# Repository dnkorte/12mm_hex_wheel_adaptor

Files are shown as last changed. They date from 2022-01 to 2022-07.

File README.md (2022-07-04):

# 12mm Hex Nut Wheel Adaptor

<h1 align="center">
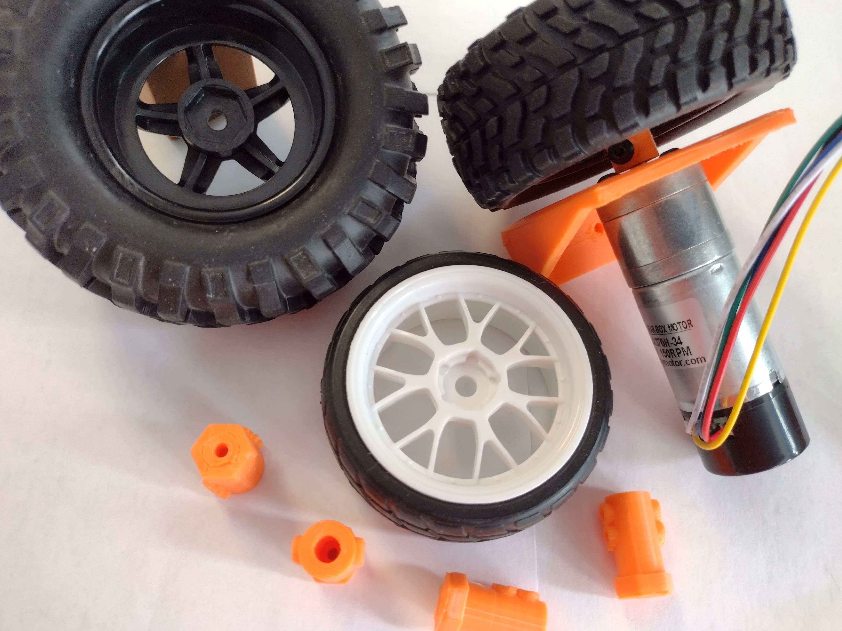
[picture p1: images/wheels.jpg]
Picture of wheels and adaptors
	<br>Sample Wheels and adaptors
</h1>

The RC (Radio Control) cars and truck hobbiest market has made be-zillions of tires/wheels available in various sizes, styles, and materials.  Just go to Amazon or  your favorite hobby store to find a huge variety.  The industry has a pretty standard mounting configuration which is based on a 12mm hex nut.  The wheels have a "socket" to hold the 12mm nut, and most RC vehicles have axles (or axle adaptors) that will fit to those nuts.  Typically the wheels attach to the 12mm nut by means of a screw at wheel center.

This project creates 3d-printable hub adaptors that mate those 12mm hex nuts to typical motor shafts used in hobby robotics -- 4mm, 5mm, and 6mm round shafts, as well as the common TT motor flattened shaft.

They are created in OpenSCAD, which is a text-based CAD tool that runs on Windows, Linux, and MAC (download it from https://openscad.org/ if you don't have it already).  Put the file provided here ("project_12mm_hex_wheel_adaptors.scad") in a folder on your computer, then open it in OpenSCAD.  Note that this tool is setup to use OpenSCAD's "customizer" feature to select the part you want, but this tool is hidden by default.  To show the customizer, just go to OpenSCAD's "View" menu and uncheck the "Hide Customizer" checkbox.

Once the customizer is visible you will see some dropdowns available (probably on the right side of your screen).  Select the "part" you want to create from the "part" dropdown (you can select the 4mm, 5mm, 6mm, or TT shaft version).  You may also select a "hub length" parameter that defines how long the adaptor is (wide tires will need longer adaptors than skinny tires), and the location for the "grub screws" that will help attach the adaptor to your motor shaft.

Whenever you change any of the dropdowns, it will redraw the image on screen.  When you have the adaptor as you wish it, click F6 or "Design/Render" on the menubar to make a finished render of the model, then select "File/Export" to save an .stl file for your printer.

The adaptor has a central hole at the "nut" end that is co-axial to the motor shaft -- this hole accepts an M3 screw to attach the adaptor to the wheel.  All screw holes are designed to be self-tapping for M3 bolts.

If your printer tolerances are different than mine you may adjust the size of the screw holes or the shaft clearance holes by editing the project_12mm_hex_wheel_adaptors.scad file.  The relevant lines are 74-84; parameters are screwhole_radius_M30_passthru, screwhole_radius_M30_selftap, and axle_clearance_gap.

The image below shows the OpenSCAD screen.  Note the Customizer menu on the right side.

<h3 align="center">
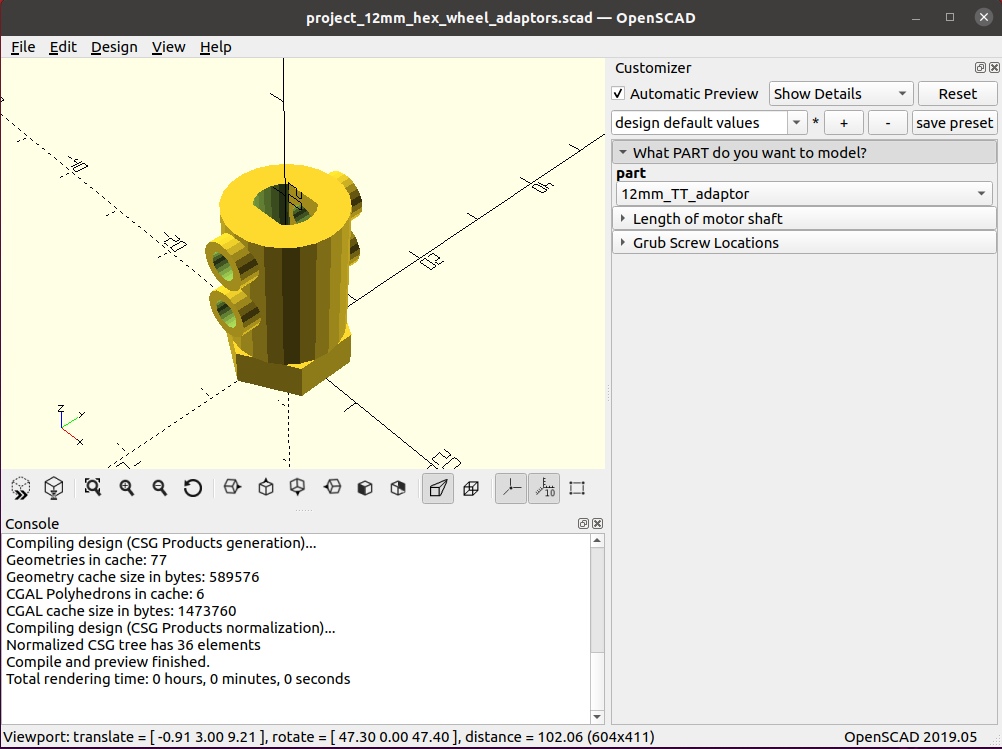
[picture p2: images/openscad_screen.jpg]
	<br>OpenSCAD screen
</h3>

The image below shows a wheel mounted on a motor shaft.
<h3 align="center">
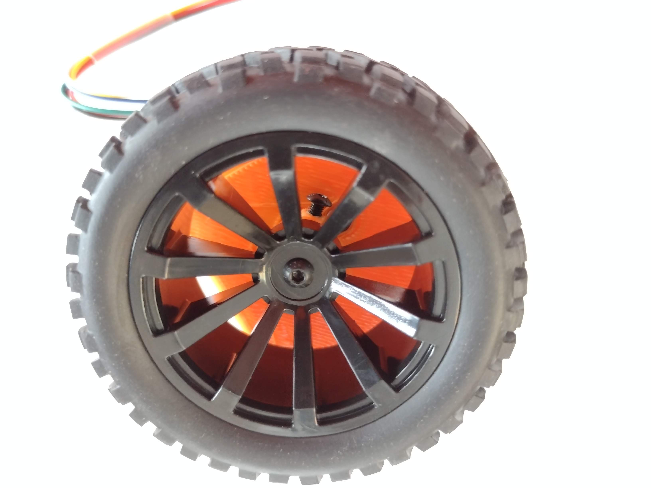
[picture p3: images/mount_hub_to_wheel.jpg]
	<br>Wheel mounted on adaptor
</h3>

A couple pre-built .stl files are included in the .stl folder here. Note that the hubs are best printed in the vertical orientation with nut end down.  They should be printed fairly slowly for best results.  

### Some sample wheels</h3>
Just as an example, some of the wheels I have used are shown here
* 95mm x 38mm wide : https://www.amazon.com/Buggy-Rubber-Tires-Spoke-Wheel/dp/B00W10IJEG  
* 76mm x 30mm wide : https://www.amazon.com/4-Pack-HobbyPark-2-99-inch-Rubber/dp/B071ZX9JB7 
* 63mm x 25mm wide : https://www.amazon.com/Tires-Wheels-Rims-Shaped-Width/dp/B01MTSMNAZ 

### Purchasable Brass Adaptors
If you prefer to use machined brass adaptors, here are some available for purchase (these are all for 12mm hex wheel end)
* 6mm motor shaft : https://www.piborg.org/motors-mounts-and-wheels-1140/hub-6mm
* 5mm motor shaft : https://www.piborg.org/motors-mounts-and-wheels-1140/hub-5mm
* 4mm motor shaft : https://www.piborg.org/motors-mounts-and-wheels-1140/hub-4mm
* 3mm motor shaft : https://www.piborg.org/motors-mounts-and-wheels-1140/hub-3mm
* 5mm motor shaft (8 pcs) : https://www.amazon.com/uxcell-Coupler-Coupling-Flexible-Connector/dp/B08M3H71SW
* 4mm motor shaft (8 pcs) : https://www.amazon.com/uxcell-Coupler-Coupling-Flexible-Connector/dp/B08M3Z2N8B

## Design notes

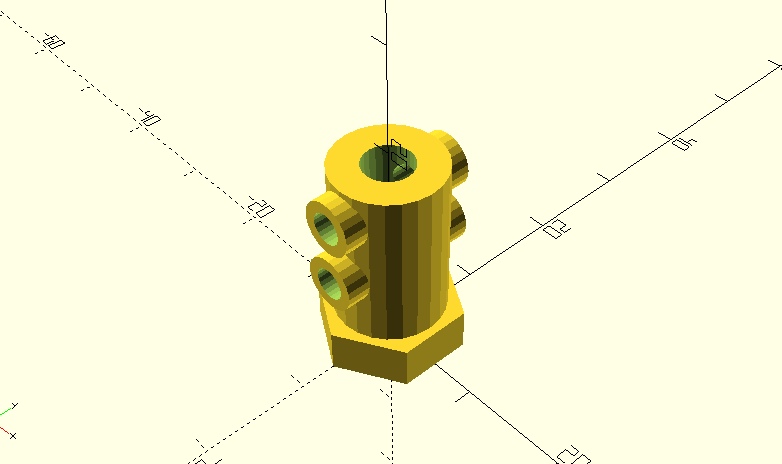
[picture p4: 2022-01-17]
images/4mm_shaft_openscad.jpg

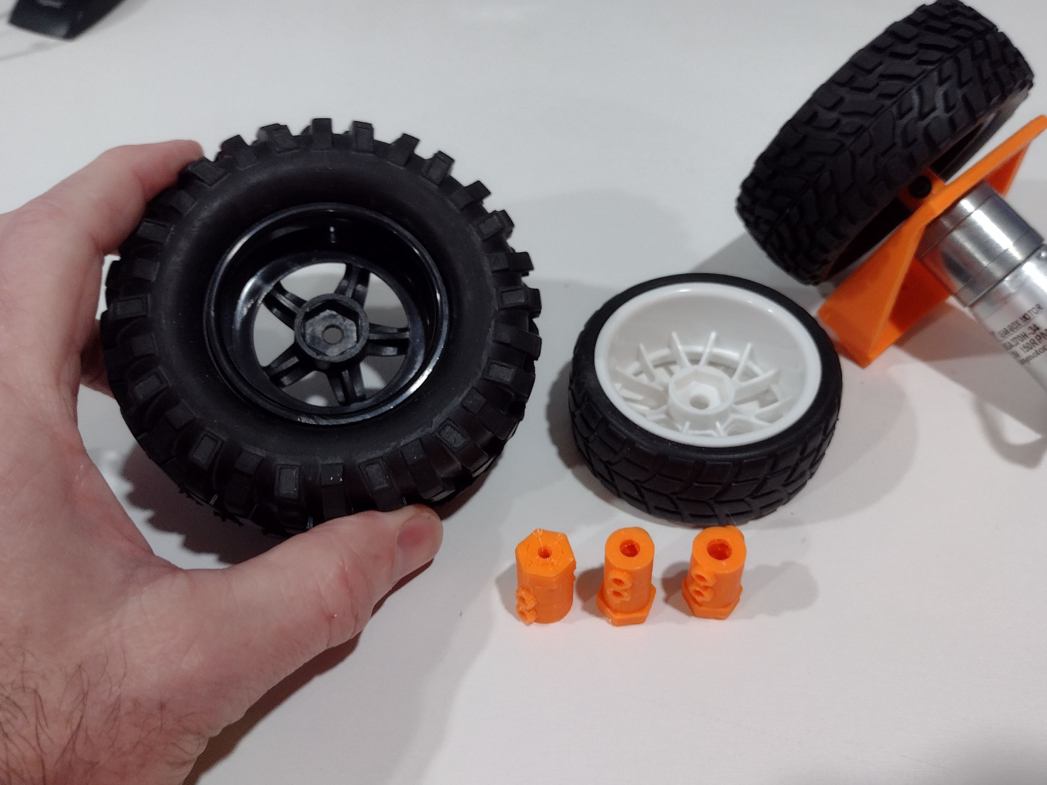
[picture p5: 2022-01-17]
images/sample_wheels.jpg

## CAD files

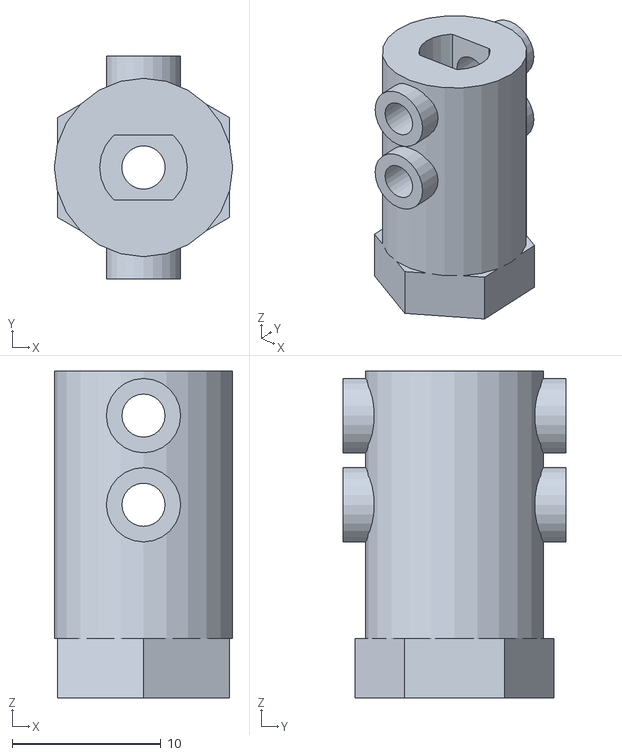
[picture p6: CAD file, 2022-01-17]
stls/TT_18mm.stl
12.0 x 15.0 x 22.0

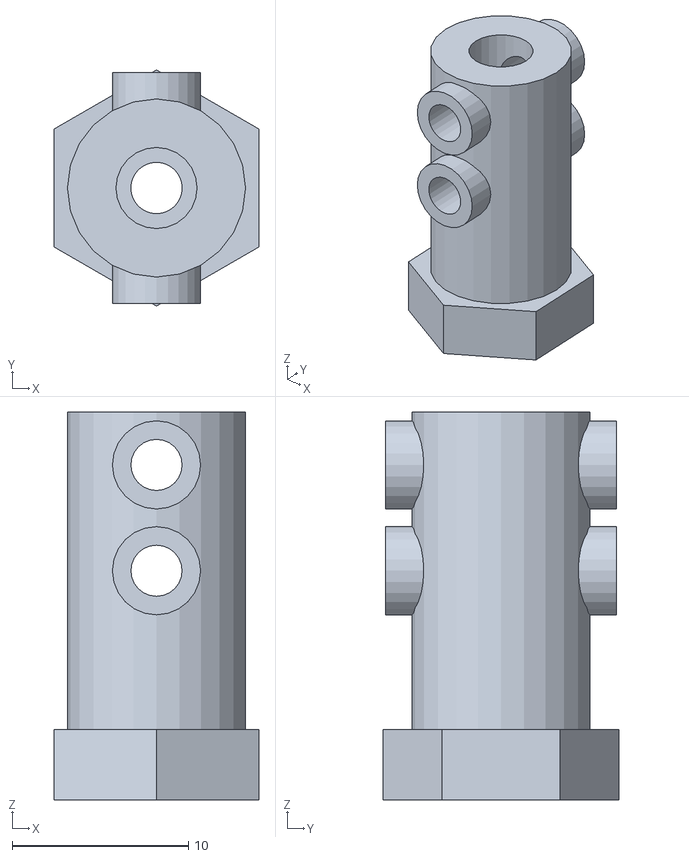
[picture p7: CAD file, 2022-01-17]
stls/4mm_axle_18mm.stl
11.6 x 13.4 x 22.0

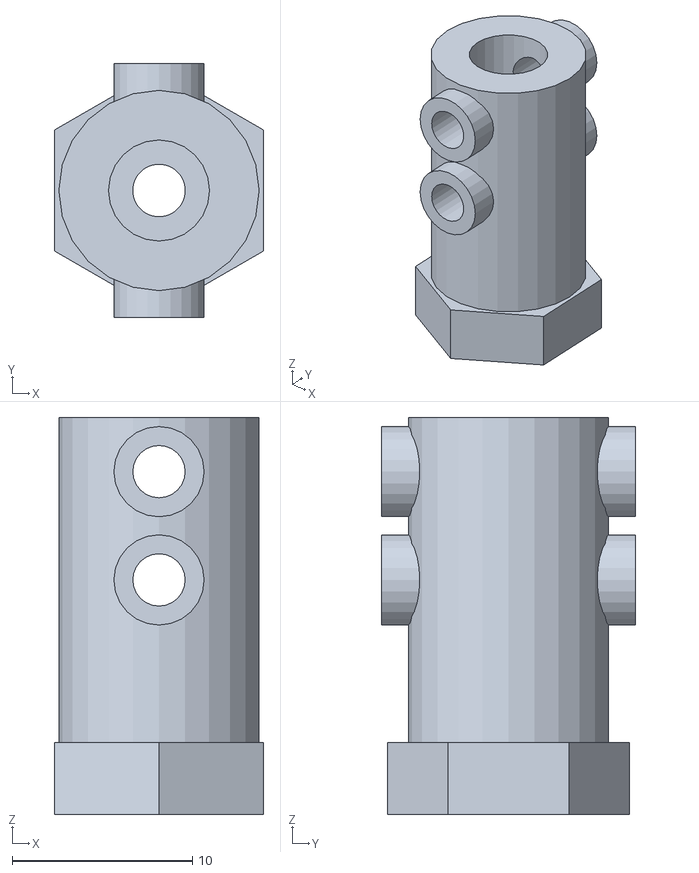
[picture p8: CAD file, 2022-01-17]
stls/5mm_axle_18mm.stl
11.6 x 14.1 x 22.0

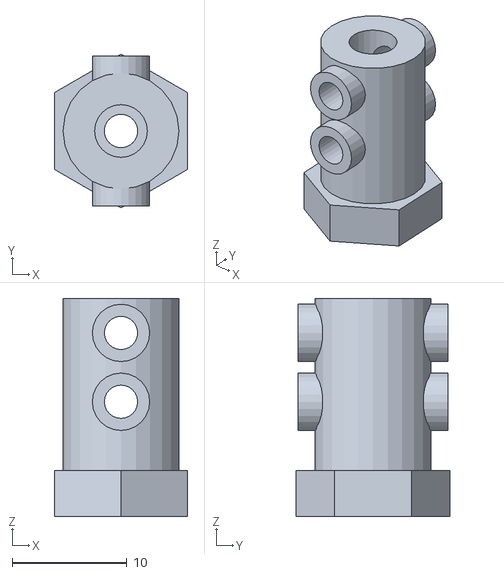
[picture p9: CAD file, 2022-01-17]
stls/4mm_axle_15mm.stl
11.6 x 13.4 x 19.0

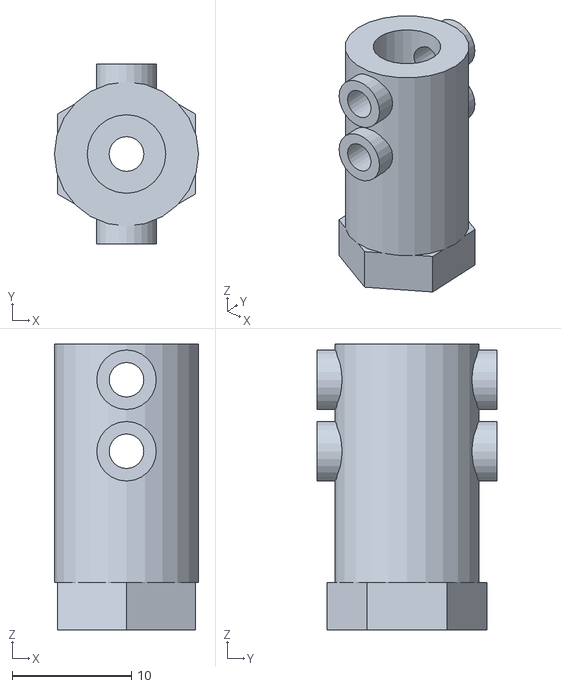
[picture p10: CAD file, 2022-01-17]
stls/6mm_axle_12mm.stl
12.1 x 15.1 x 24.0

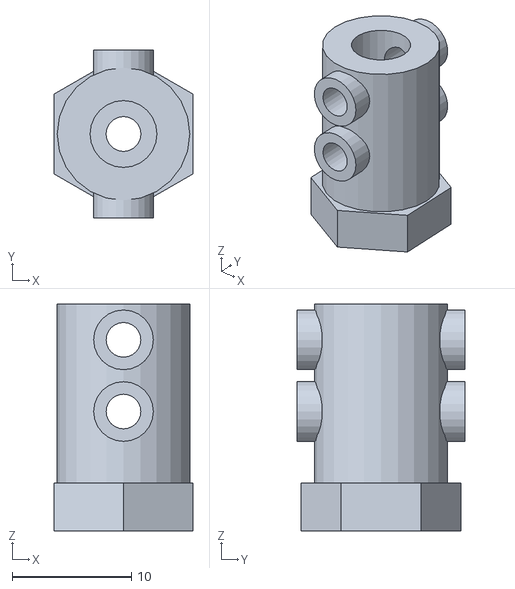
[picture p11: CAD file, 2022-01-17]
stls/5mm_axle_15mm.stl
11.6 x 14.1 x 19.0

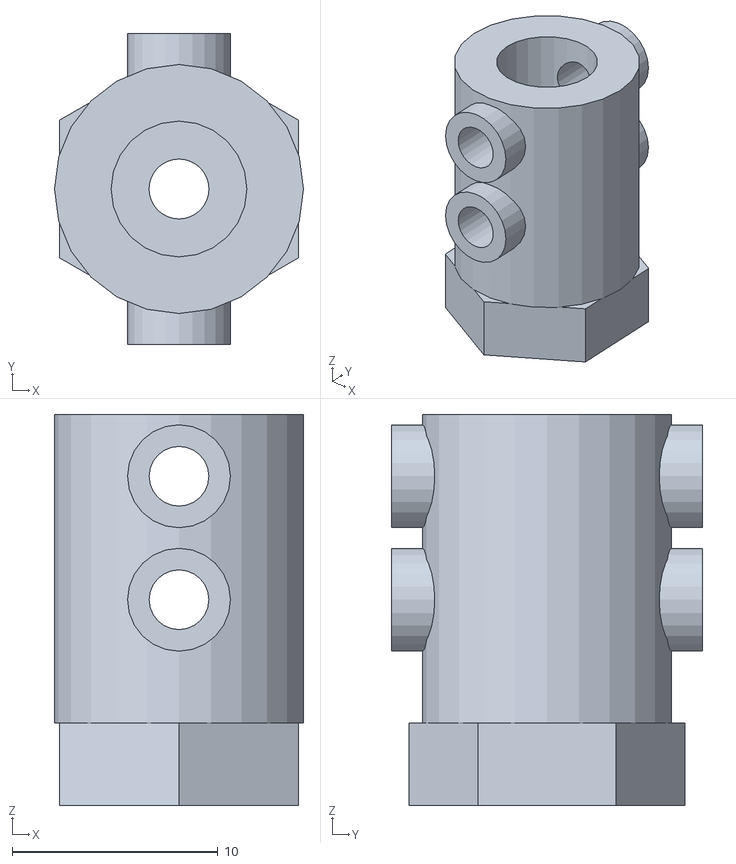
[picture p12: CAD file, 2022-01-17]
stls/6mm_axle_18mm.stl
12.1 x 15.1 x 19.0

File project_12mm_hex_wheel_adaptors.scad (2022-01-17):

/*
 * Module: project_12mm_hex_wheel_adaptors.scad
 * this generates an adaptor the connects standard RC wheel 12mm hex nut
 *   wheels to standard robotics motor hubs  
 *
 *   NOTE that hub adaptors should be printed slowly -- about 50% normal print speed 
 *
 * Author(s): Don Korte 
 *
 * github: https://github.com/dnkorte/
 *  
 * MIT License
 * 
 * Copyright (c) 2022 Don Korte
 * 
 * Permission is hereby granted, free of charge, to any person obtaining a copy
 * of this software and associated documentation files (the "Software"), to deal
 * in the Software without restriction, including without limitation the rights
 * to use, copy, modify, merge, publish, distribute, sublicense, and/or sell
 * copies of the Software, and to permit persons to whom the Software is
 * furnished to do so, subject to the following conditions:
 * 
 * The above copyright notice and this permission notice shall be included in all
 * copies or substantial portions of the Software.
 * 
 * THE SOFTWARE IS PROVIDED "AS IS", WITHOUT WARRANTY OF ANY KIND, EXPRESS OR
 * IMPLIED, INCLUDING BUT NOT LIMITED TO THE WARRANTIES OF MERCHANTABILITY,
 * FITNESS FOR A PARTICULAR PURPOSE AND NONINFRINGEMENT. IN NO EVENT SHALL THE
 * AUTHORS OR COPYRIGHT HOLDERS BE LIABLE FOR ANY CLAIM, DAMAGES OR OTHER
 * LIABILITY, WHETHER IN AN ACTION OF CONTRACT, TORT OR OTHERWISE, ARISING FROM,
 * OUT OF OR IN CONNECTION WITH THE SOFTWARE OR THE USE OR OTHER DEALINGS IN THE
 * SOFTWARE.
 */


/* [What PART do you want to model?] */
part = "12mm_4mm_adaptor";  // [ "12mm_6mm_adaptor", "12mm_5mm_adaptor", "12mm_4mm_adaptor", "12mm_TT_adaptor" ]

/* [Length of motor shaft] */
// length of "round" part of adaptor that surrounds axle
hub_len = 15;   // [12, 15, 18, 20 ]

/* [Grub Screw Locations] */
// distance of "first" grub screw from end of adaptor
grubscrew_dist_from_end = 3;    // [ 3, 4, 5, 6 ]
// distance between grub screws
grubscrew_separation = 6;       // [ 5, 6, 7, 8 ] 

draw_part();

module draw_part() {
    $fn = 24;

    if (part == "12mm_6mm_adaptor") {
        draw_12mm_6mm_adaptor();
    }
    if (part == "12mm_5mm_adaptor") {
        draw_12mm_5mm_adaptor();
    }
    if (part == "12mm_4mm_adaptor") {
        draw_12mm_4mm_adaptor();
    }
    if (part == "12mm_TT_adaptor") {
        draw_12mm_TT_adaptor();
    }
}
/*
 * hub adaptor parameters that are not displayed in OpenScad Customizer
 */

// standard parameters for all parts
screwhole_radius_M30_passthru = 2;  
screwhole_radius_M30_selftap = 1.45;
axle_clearance_gap = 0.6;   // allowance for 3d printer "slop" + slide fit


// parameters for the 12mm nut
screwhole_dia_wheel_attachment_screw = (screwhole_radius_M30_selftap * 2);
width_across_flats = 11.6;
nut_thick = 4;



module draw_12mm_6mm_adaptor() {
    motor_shaft_dia = 6 + axle_clearance_gap;
    hub_dia = motor_shaft_dia + 5.5;

    g1 = hub_len - grubscrew_dist_from_end;
    g2 = hub_len - grubscrew_dist_from_end - grubscrew_separation;

    make_hex_nut(width_across_flats, nut_thick, screwhole_dia_wheel_attachment_screw);
    
    translate([ 0, 0, nut_thick ]) difference() {
        union() {
            cylinder(d=hub_dia, h=hub_len);
            translate([ 0, -(hub_dia+3)/2, g1 ]) rotate([  -90, 0, 0  ])  cylinder( d=5, h=hub_dia+3);
            translate([ 0, -(hub_dia+3)/2, g2 ]) rotate([  -90, 0, 0  ])  cylinder( d=5, h=hub_dia+3);
        }
        translate([ 0, 0, -0.1 ]) cylinder(d=motor_shaft_dia, h=hub_len + 0.2);
        translate([ 0, -((hub_dia+3)/2)-0.1, g1 ]) rotate([  -90, 0, 0  ])  cylinder( r= screwhole_radius_M30_selftap, h=hub_dia+3.2);
        translate([ 0, -((hub_dia+3)/2)-0.1, g2 ]) rotate([  -90, 0, 0  ])  cylinder( r= screwhole_radius_M30_selftap, h=hub_dia+3.2);
    } 
}


module draw_12mm_5mm_adaptor() {
    motor_shaft_dia = 5 + axle_clearance_gap;
    hub_dia = motor_shaft_dia + 5.5;

    g1 = hub_len - grubscrew_dist_from_end;
    g2 = hub_len - grubscrew_dist_from_end - grubscrew_separation;


    make_hex_nut(width_across_flats, nut_thick, screwhole_dia_wheel_attachment_screw);
    
    translate([ 0, 0, nut_thick ]) difference() {
        union() {
            cylinder(d=hub_dia, h=hub_len);
            translate([ 0, -(hub_dia+3)/2, g1 ]) rotate([  -90, 0, 0  ])  cylinder( d=5, h=hub_dia+3);
            translate([ 0, -(hub_dia+3)/2, g2 ]) rotate([  -90, 0, 0  ])  cylinder( d=5, h=hub_dia+3);
        }
        translate([ 0, 0, -0.1 ]) cylinder(d=motor_shaft_dia, h=hub_len + 0.2);
        translate([ 0, -((hub_dia+3)/2)-0.1, g1 ]) rotate([  -90, 0, 0  ])  cylinder( r= screwhole_radius_M30_selftap, h=hub_dia+3.2);
        translate([ 0, -((hub_dia+3)/2)-0.1, g2 ]) rotate([  -90, 0, 0  ])  cylinder( r= screwhole_radius_M30_selftap, h=hub_dia+3.2);
    } 
}

module draw_12mm_4mm_adaptor() {
    motor_shaft_dia = 4 + axle_clearance_gap;
    hub_dia = motor_shaft_dia + 5.5;

    g1 = hub_len - grubscrew_dist_from_end;
    g2 = hub_len - grubscrew_dist_from_end - grubscrew_separation;


    make_hex_nut(width_across_flats, nut_thick, screwhole_dia_wheel_attachment_screw);
    
    translate([ 0, 0, nut_thick ]) difference() {
        union() {
            cylinder(d=hub_dia, h=hub_len);
            translate([ 0, -(hub_dia+3)/2, g1 ]) rotate([  -90, 0, 0  ])  cylinder( d=5, h=hub_dia+3);
            translate([ 0, -(hub_dia+3)/2, g2 ]) rotate([  -90, 0, 0  ])  cylinder( d=5, h=hub_dia+3);
        }
        translate([ 0, 0, -0.1 ]) cylinder(d=motor_shaft_dia, h=hub_len + 0.2);
        translate([ 0, -((hub_dia+3)/2)-0.1, g1 ]) rotate([  -90, 0, 0  ])  cylinder( r= screwhole_radius_M30_selftap, h=hub_dia+3.2);
        translate([ 0, -((hub_dia+3)/2)-0.1, g2 ]) rotate([  -90, 0, 0  ])  cylinder( r= screwhole_radius_M30_selftap, h=hub_dia+3.2);
    } 
}

module draw_12mm_TT_adaptor() {
    TT_shaft_dia = 5.3 + axle_clearance_gap;
    TT_shaft_flatwidth = 3.8 + axle_clearance_gap;
    hub_dia = 12;

    g1 = hub_len - grubscrew_dist_from_end;
    g2 = hub_len - grubscrew_dist_from_end - grubscrew_separation;

    make_hex_nut(width_across_flats, nut_thick, screwhole_dia_wheel_attachment_screw);
    
    translate([ 0, 0, nut_thick ]) difference() {
        union() {
            cylinder(d=hub_dia, h=hub_len);
            translate([ 0, -(hub_dia+3)/2, g1 ]) rotate([  -90, 0, 0  ])  cylinder( d=5, h=hub_dia+3);
            translate([ 0, -(hub_dia+3)/2, g2 ]) rotate([  -90, 0, 0  ])  cylinder( d=5, h=hub_dia+3);
        }
        translate([ 0, 0, -0.1 ]) shaft_flat(TT_shaft_dia, TT_shaft_flatwidth, hub_len + 0.2, orientation="wide");

        translate([ 0, -((hub_dia+3)/2)-0.1, g1 ]) rotate([  -90, 0, 0  ])  cylinder( r= screwhole_radius_M30_selftap, h=hub_dia+3.2);
        translate([ 0, -((hub_dia+3)/2)-0.1, g2 ]) rotate([  -90, 0, 0  ])  cylinder( r= screwhole_radius_M30_selftap, h=hub_dia+3.2);
    } 
}


/*
 * module prism generates a basic "wedge" shape that can be used vertically to make support-less
 * 3d-printable shelves; this is defined in openSCAD documetation at:
 *      https://en.wikibooks.org/wiki/OpenSCAD_User_Manual/Primitive_Solids
 */

module prism(l, w, h){
   polyhedron(
           points=[[0,0,0], [l,0,0], [l,w,0], [0,w,0], [0,w,h], [l,w,h]],
           faces=[[0,1,2,3],[5,4,3,2],[0,4,5,1],[0,3,4],[5,2,1]]
           );
}

/*
 * ***************************************************************************
 * module shaft_flat() makes a flattened shaft
 * this is a round cylinder, with flats on 2 sides (ie for a TT motor)
 *  
 * this is generated in xy plane, centered at origin, pointed "up" (towards + Z)
 * it should be "added" to design, there are no holes needed at placement level
 *
 * for TT motor, assume actual 5.3 diameter, with flatwidth 3.8mm;  but leave clearance gap too
 *
 * parameters:
 *      diameter    diameter of round part of shaft, in mm
 *      flatwidth   dimension across flat part in mm (flat-to-flat)
 *      length      length (or height) of shaft
 *      orientation "tall" or "wide" 
 *          (for tall, initial flats are on left/right (+/- x sides))
 * ***************************************************************************
 */
module shaft_flat(diameter, flatwidth, length, orientation="tall") {
    remove_from_each_side = (diameter - flatwidth) / 2;
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

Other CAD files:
stls/TT_15mm.stl

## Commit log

2022-01-17 added sample wheels
2022-07-04 added links for purchasable brass adaptors; also updated openscad model to include options for threaded inserts instead of self-tapping screws
